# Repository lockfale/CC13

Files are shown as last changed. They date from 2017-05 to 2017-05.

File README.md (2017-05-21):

# CC13:
CarolinaCon13 Badge Jank

## Files:
- CC13 Badge.pdf - Detailed badge assembly guide
- ino files

## If you need to setup an Arduino build environment:

Download the latest Arduino archive from https://www.arduino.cc/en/Main/Software

Uncompress archive: xz --decompress arduino-1.8.2-linux64.tar.xz

As root untar in /usr/local and create symlink:
```
    # cd /usr/local
    # tar xvf ~/Downloads/arduino-1.8.2-linux64.tar
    # ln -s arduino-1.8.2/ arduino
```

As regular user, download badge code into home directory (--recursive will pull down dependency projects):
```
    cd
    git clone --recursive https://github.com/lockfale/CC13.git
```

## LED Patterns

To add an LED pattern:
  # In `badge/led.cpp`:
    ## Add a `const byte` array to with its own name and each sequential animation state of your desired LED pattern in binary format matching the number of LEDs in each entry.
    ## Add a branch to the `changePattern` function.
    ## Add a function for it at the bottom.
  # In `badge/led.h`:
    ## Add a function for it at the bottom.
  # In `badge/setup.cpp`:
    ## Add a submenu command for it.

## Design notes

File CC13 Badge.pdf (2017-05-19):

# CarolinaCon 13 Badge Guide

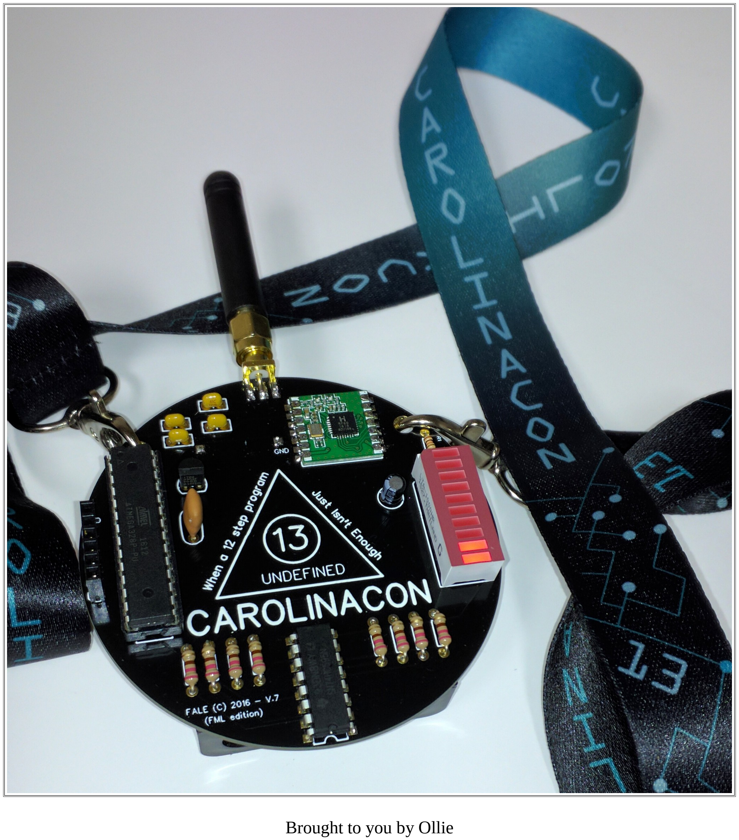
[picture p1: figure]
Brought to you by Ollie

Hello you lovely hackers, crackers, and slackers. Welcome to another year of CarolinaCon.

We'll skip over the 'how to solder' portion of the guide. If you've never soldered before don't feel bad as there should be plenty of folks in the Hardware Hacking Village willing to walk you along.

First off make sure your bag has the proper bits:

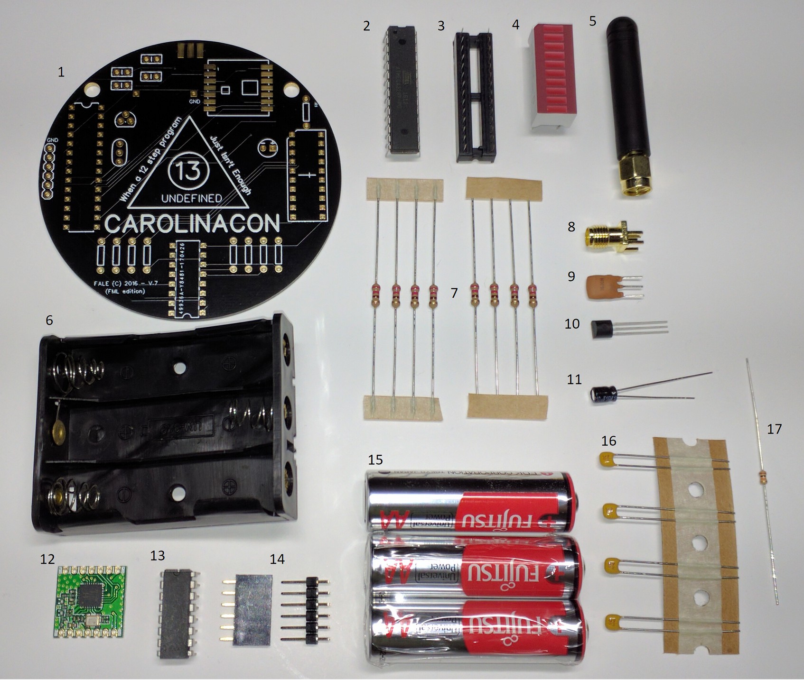
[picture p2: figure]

1. Badge*
2. Atmel Chip
3. Chip Socket
4. LED Array
5. Antenna
6. Battery Holder
7. 8x 220ohm Resistor
8. Connector for Antenna**
9. Timing Crystal
10. 3.3v Regulator
11. Electrolytic Capacitor
12. Transceiver Chip
13. Shift Register
14. Male & Female Headers
15. 3x AA Batteries
16. 4x Polymer Capacitors
17. 10k Resistor

Replacements are available for missing or broken parts but quantity is limited on some items.

* | Yours most likely isn't as cool as this one, probably green or something.
** | If you were late to reregistration you may regretfully have gotten a bag without a SMA
| Connector for the Antenna. Your badge can still play with the others but you will have a wire
| Antenna instead.

These parts can be soldered in any order but I would suggest the ones that are directional first.

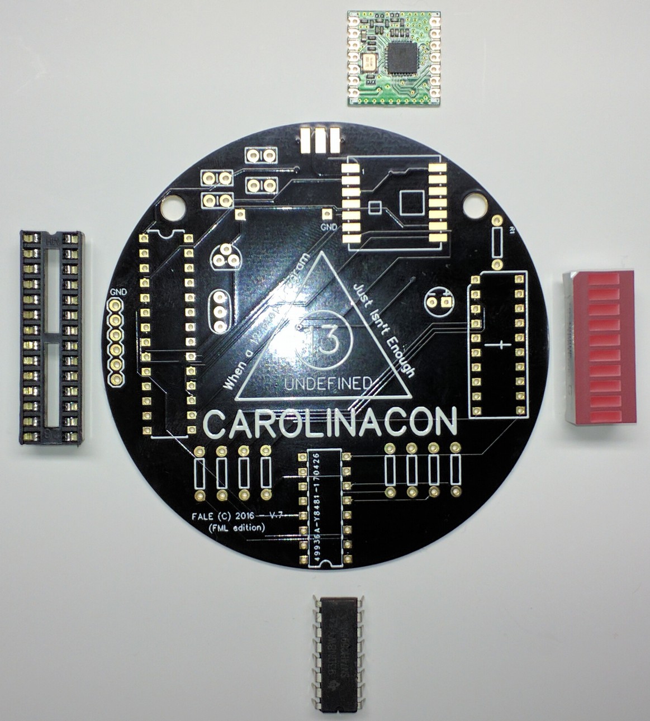
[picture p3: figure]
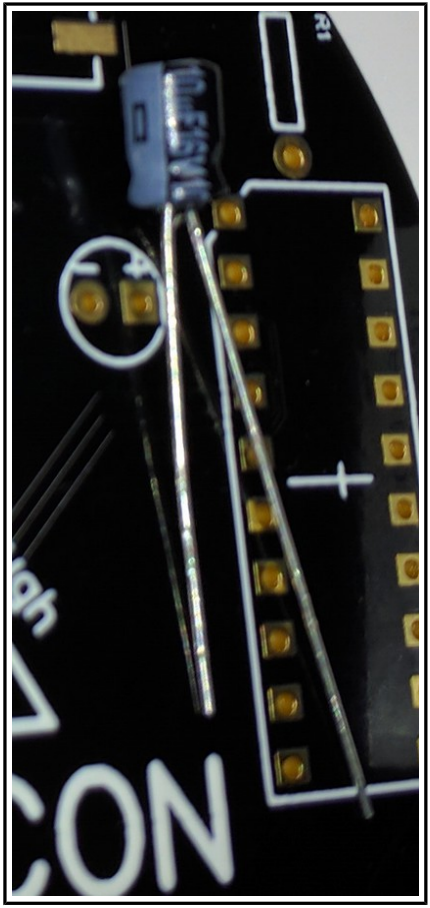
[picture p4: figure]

The Chip Socket, Shift Register, Led Array, and Transceiver Chip all have illustrations on the board to ensure that they are set in the right direction.

The Electrolytic Capacitor has a gray bar down one side that indicates the negative lead.

Finished product:

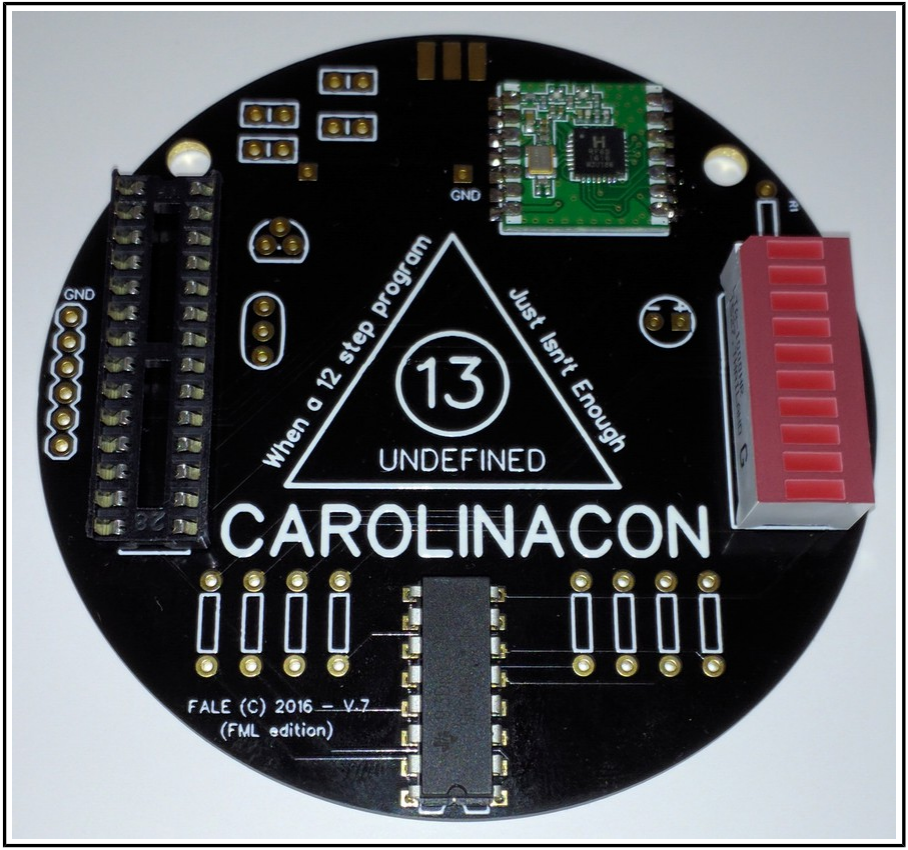
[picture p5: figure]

It should be noted that it is not a good idea to insert the Atmel Chip into the socket until the rest of the badge is finished and the Atmel Chip has had its boot loader installed. This can be done by the guys in the Hardware Hacking Village.

Next step is the rest of the badge:

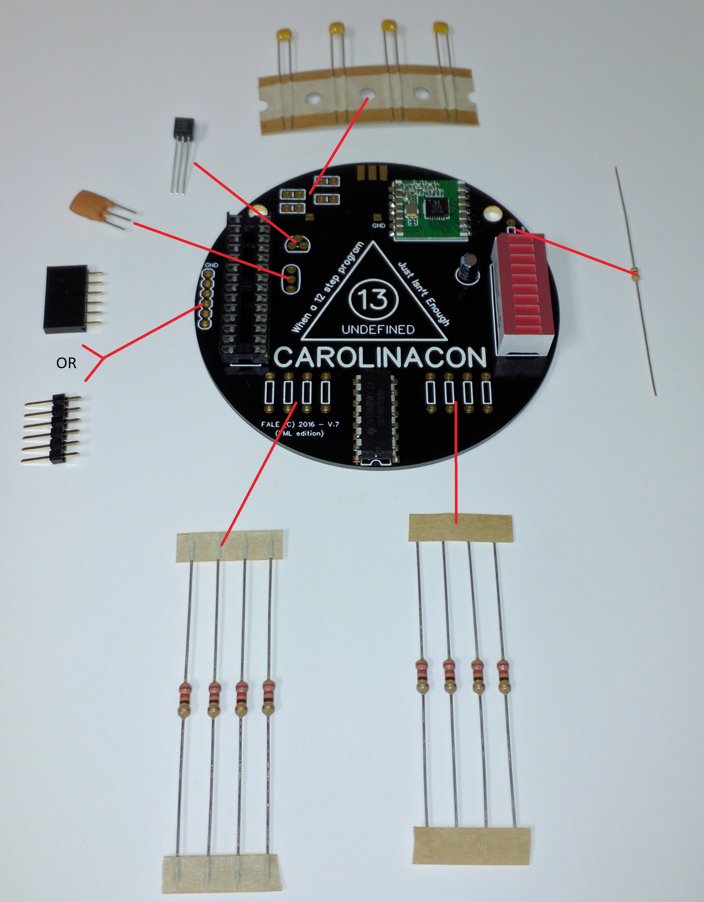
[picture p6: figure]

On the Voltage Regulator make sure the middle leg goes to the single pin well towards the top of the badge and the outer legs go to their respective pin wells bellow it. The Timing Crystal, Resistors, and Polymer Capacitors can be inserted in any direction.

Use the Female Header if you want to program the badge using the equipment provided. Use the Male Header if you have your own ideas for the badge.

Next step is the antenna:

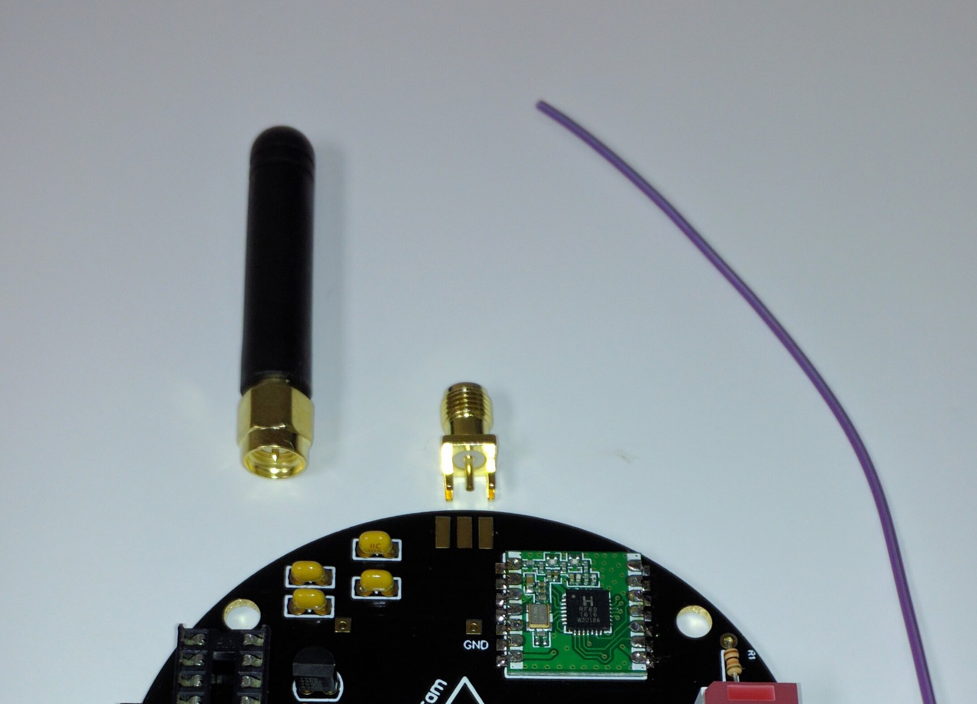
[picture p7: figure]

If you have the SMA connector solder the side with three prongs to the strip of three solder points at the top of the badge. If you only have a wire antenna, strip a 1/8th inch section and solder that to the middle solder joint on the top. Liberal use of adhesive is suggested to keep the wire antenna attached by more than just the solder.

Next is the battery pack:

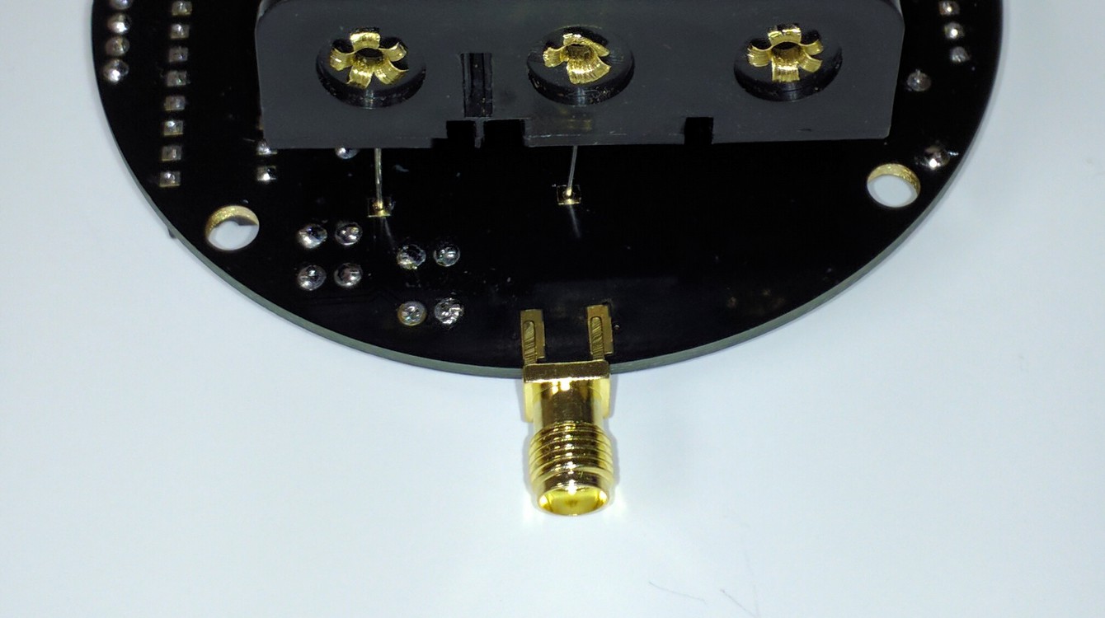
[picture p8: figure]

On the reverse side of the badge you will only have two pin wells left, the battery pack leads go through here. You can also solder the other side of the SMA connector at this time. Double sided tape will be available at the Hardware Hacking Village to secure the battery pack to the badge.

Your badge is finished as far as the hardware is concerned, now all that’s left is to flash some software, either what our volunteers have provided or some home brew of your own.

Have fun and welcome to CC13.

- Ollie the Miniature Australian Shepherd.

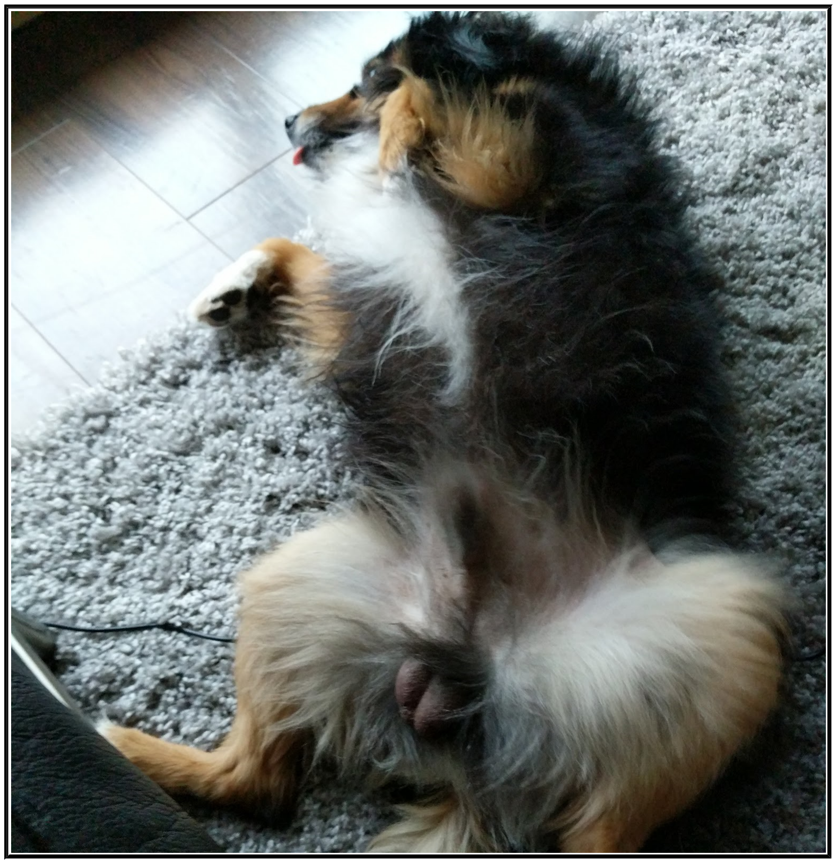
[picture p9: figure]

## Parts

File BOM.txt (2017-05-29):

1x IC 8-BIT SHIFT REGISTER 16-DIP 	- SN74HC595N 		- DIGIKEY PART NUMBER 296-1600-5-ND 
1x CONN IC DIP SOCKET 28POS TIN   	- ED281DT	 		- DIGIKEY PART NUMBER ED3050-5-ND
1x IC MCU 8BIT 32KB FLASH 28DIP		- ATMEGA328P-PU   	- DIGIKEY PART NUMBER ATMEGA328P-PU-ND
4x CAP CER 0.1UF 50V Y5V RADIAL		- K104Z15Y5VF5TL2 	- DIGIKEY PART NUMBER BC1160CT-ND 
1x CER RES 16.0000MHZ 30PF 			- ZTT-16.00MX		- X908-ND 
1x LED BAR GRAPH 10-SEGMENT RED		- LTA-1000HR		- 160-1066-ND 
1x RES 10K OHM 1/6W 5% AXIAL		- CFR-12JB-52-10K	- 10KEBK-ND
8x RES 220 OHM 1/4W 5% AXIAL		- CF14JT220R		- CF14JT220RCT-ND 
1x IC REG LDO 3.3V 0.25A TO92-3		- MCP1702-3302E/TO 	- MCP1702-3302E/TO-ND 
1x CAP ALUM 10UF 20% 16V RADIAL		- ECE-A1CKS100		- P966-ND
1x tranciever http://www.anarduino.com/details.jsp?pid=146
PCB edge mount female SMA connector, no part number, check amazon or ebay.
any 3 cell AAA or AA battery holder should work, find one with wire leads to ensure compatability.
any 8 pin .1" spacing male or female header for the FTDI connector.

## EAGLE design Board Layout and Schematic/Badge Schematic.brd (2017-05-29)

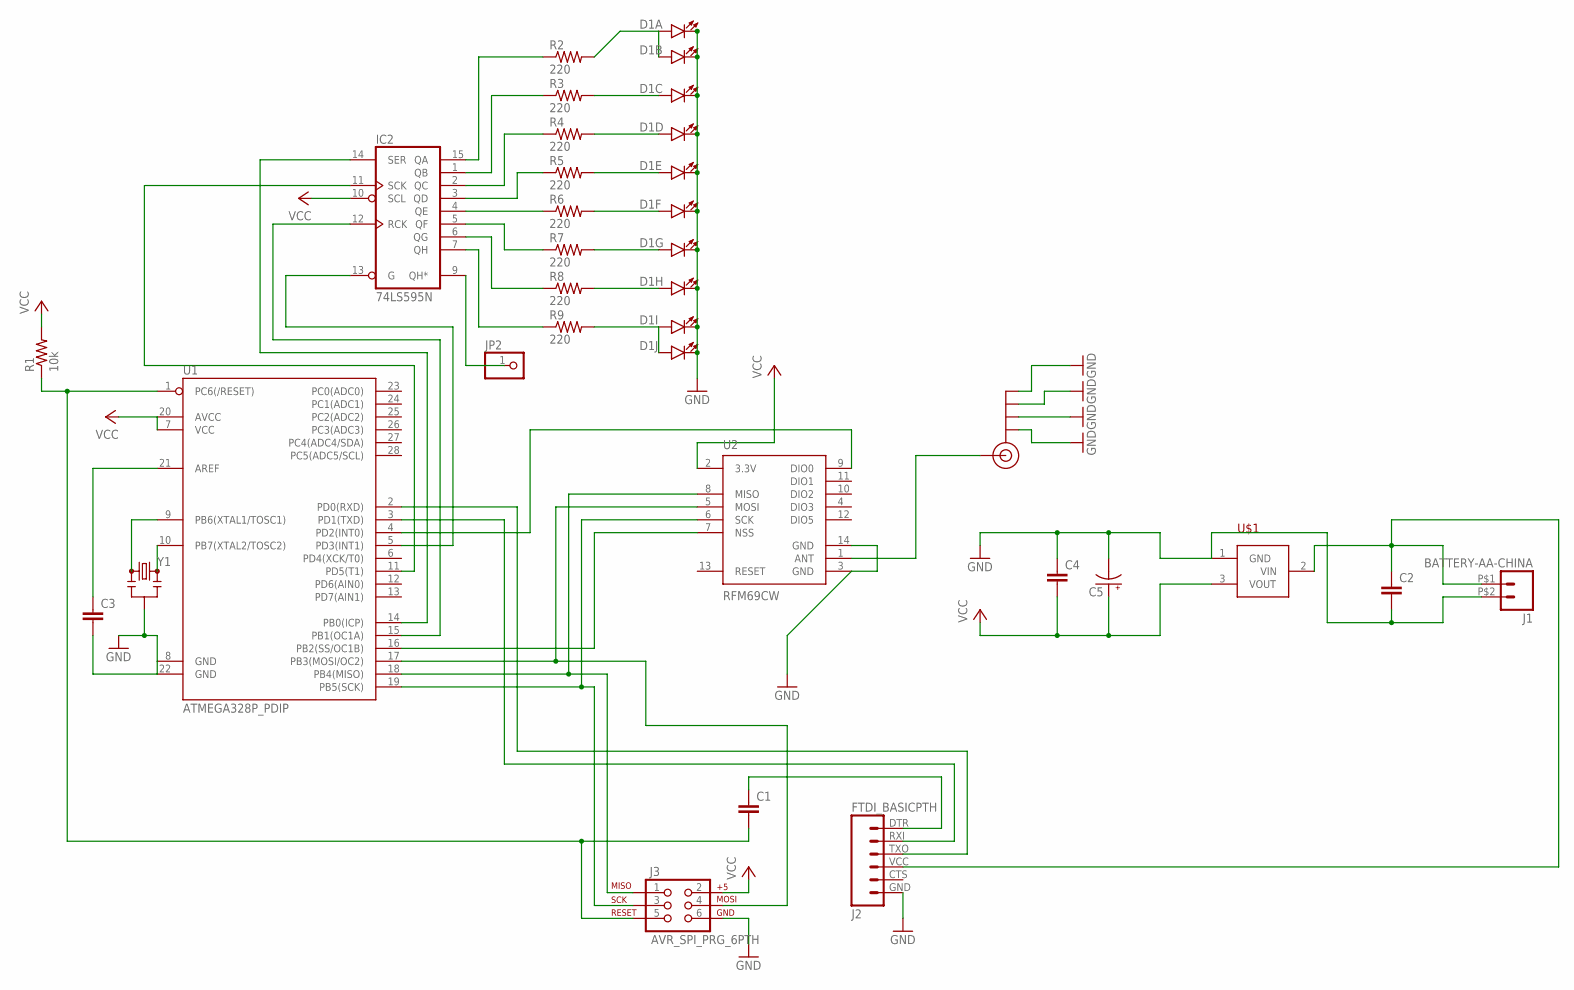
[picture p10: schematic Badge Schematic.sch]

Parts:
C1, C2, C3, C4: 0.1UF-50V-20%(PTH)KIT-EZ; CAP-PTH-SMALL-KIT
C5: 10UF-25V-20%(PTH)KIT; CPOL-RADIAL-10UF-25V-KIT
D1: LED_BARGRAPH_10; LED_BARGAPH_10
IC2: 74LS595N; DIL16
J1: BATTERY-AA-CHINA; BATTERY-AA-CHINA-PACKAGE
J2: FTDI_BASICPTH; FTDI_BASIC
J3: AVR_SPI_PRG_6PTH; 2X3
J$1: SMA_EDGE; SMA-EDGE
JP2: PINHD-1X1; 1X01
R1: 10k; AXIAL-0.3
R2, R3, R4, R5, R6, R7, R8, R9: 220; AXIAL-0.3EZ
U1: ATMEGA328P_PDIP; DIL28-3
U2: RFM69CW; RFM69CW-XXXS2
U$1: MCP1702-33TO92; TO-92
Y1: RESONATORPTH; RESONATOR-PTH

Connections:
GND: C2.2, C3.2, C4.1, C5.2 (-), D1.11 (C), D1.12 (C), D1.13 (C), D1.14 (C), D1.15 (C), D1.16 (C), D1.17 (C), D1.18 (C), D1.19 (C), D1.20 (C), IC2.8 (GND), J1.P$2 (2), J2.GND (6), J3.6, J$1.GND@0 (GND), J$1.GND@1 (GND), J$1.GND@2 (GND), J$1.GND@3 (GND), U1.8 (GND), U1.22 (GND), U2.3 (GND), U2.14 (GND), U$1.1 (GND), Y1.2
unnamed: J$1.SIG (SIGNAL), U2.1 (ANT)
unnamed: J3.4, U1.17 (PB3(MOSI/OC2)), U2.5 (MOSI)
unnamed: J3.1, U1.18 (PB4(MISO)), U2.8 (MISO)
unnamed: J3.3, U1.19 (PB5(SCK)), U2.6 (SCK)
unnamed: U1.4 (PD2(INT0)), U2.9 (DIO0)
unnamed: U1.16 (PB2(SS/OC1B)), U2.7 (NSS)
unnamed: IC2.13 (G), U1.5 (PD3(INT1))
unnamed: C1.1, J2.DTR (1)
unnamed: U1.10 (PB7(XTAL2/TOSC2)), Y1.3
unnamed: J2.TXO (3), U1.2 (PD0(RXD))
unnamed: J2.RXI (2), U1.3 (PD1(TXD))
unnamed: U1.9 (PB6(XTAL1/TOSC1)), Y1.1
unnamed: C2.1, J1.P$1 (1), J2.VCC (4), U$1.2 (VIN)
unnamed: IC2.7 (QH), R9.P$1 (1)
unnamed: IC2.15 (QA), R2.P$1 (1)
unnamed: IC2.6 (QG), R8.P$1 (1)
unnamed: IC2.5 (QF), R7.P$1 (1)
unnamed: C3.1, U1.21 (AREF)
unnamed: IC2.4 (QE), R6.P$1 (1)
unnamed: C1.2, J3.5, R1.P$1 (1), U1.1 (PC6(/RESET))
unnamed: IC2.3 (QD), R5.P$1 (1)
unnamed: IC2.2 (QC), R4.P$1 (1)
unnamed: IC2.1 (QB), R3.P$1 (1)
unnamed: D1.1 (A), D1.2 (A), R2.P$2 (2)
unnamed: D1.3 (A), R3.P$2 (2)
unnamed: D1.4 (A), R4.P$2 (2)
unnamed: D1.5 (A), R5.P$2 (2)
unnamed: D1.6 (A), R6.P$2 (2)
unnamed: D1.7 (A), R7.P$2 (2)
unnamed: D1.8 (A), R8.P$2 (2)
unnamed: D1.9 (A), D1.10 (A), R9.P$2 (2)
unnamed: IC2.14 (SER), U1.14 (PB0(ICP))
unnamed: IC2.12 (RCK), U1.15 (PB1(OC1A))
unnamed: IC2.11 (SCK), U1.11 (PD5(T1))
unnamed: IC2.9 (QH*), JP2.1
VCC: C4.2, C5.1 (+), IC2.10 (SCL), IC2.16 (VCC), J3.2, R1.P$2 (2), U1.7 (VCC), U1.20 (AVCC), U2.2 (3.3V), U$1.3 (VOUT)

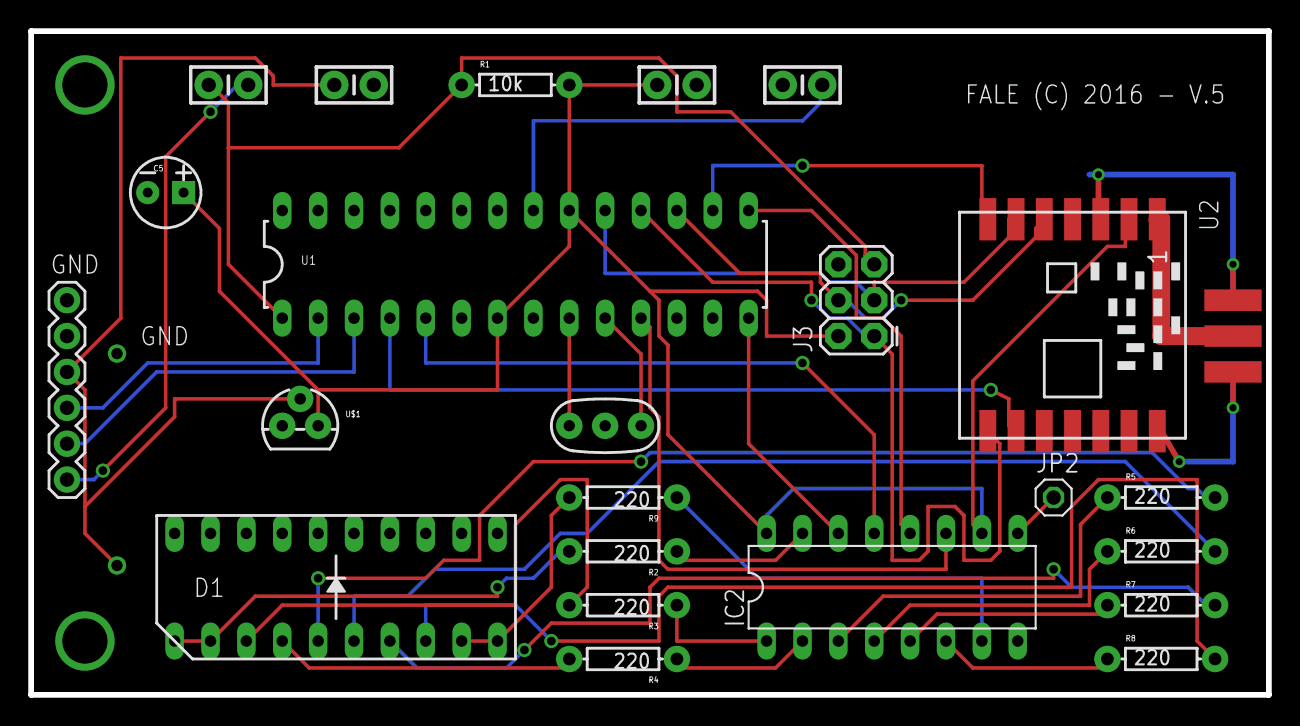
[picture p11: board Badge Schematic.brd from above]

Board: 2 copper layers, 87.6 x 47.0 mm, 25 parts (0 on the bottom side), 37 nets.

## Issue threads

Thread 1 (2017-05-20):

Missing SerialUI.h

snuffeluffegus, 2017-05-20:
wtf volvo why no SerialUI.h

pls give

melvin2001, 2017-05-20:
have you tried turning it off and on again

pandatrax, 2017-05-22:
Rebooted. This is fine.

Pysis868, 2017-05-24:
**Solved now**

..... Why am **I** getting this now?!

```
~/P/C/badge (master ⚡↩☡=) make
-------------------------
Arduino.mk Configuration:
- [AUTODETECTED]       CURRENT_OS = MAC
- [USER]               ARDUINO_DIR = /Applications/Arduino.app/Contents/Java
- [USER]               ARDMK_DIR = ../Arduino-Makefile//../Arduino-Makefile//../Arduino-Makefile
- [AUTODETECTED]       ARDUINO_VERSION = 182
- [DEFAULT]            ARCHITECTURE = avr
- [DEFAULT]            ARDMK_VENDOR = arduino
- [AUTODETECTED]       ARDUINO_PREFERENCES_PATH = /Users/Pysis/Library/Arduino15/preferences.txt
- [AUTODETECTED]       ARDUINO_SKETCHBOOK = /Users/Pysis/Documents/Arduino (from arduino preferences file)
- [BUNDLED]            AVR_TOOLS_DIR = /Applications/Arduino.app/Contents/Java/hardware/tools/avr (in Arduino distribution)
- [COMPUTED]           ARDUINO_LIB_PATH = /Applications/Arduino.app/Contents/Java/libraries (from ARDUINO_DIR)
- [COMPUTED]           ARDUINO_PLATFORM_LIB_PATH = /Applications/Arduino.app/Contents/Java/hardware/arduino/avr/libraries (from ARDUINO_DIR)
- [COMPUTED]           ARDUINO_VAR_PATH = /Applications/Arduino.app/Contents/Java/hardware/arduino/avr/variants (from ARDUINO_DIR)
- [COMPUTED]           BOARDS_TXT = /Applications/Arduino.app/Contents/Java/hardware/arduino/avr/boards.txt (from ARDUINO_DIR)
- [USER]               USER_LIB_PATH = /Users/Pysis/Programming/CC13/libraries
- [DEFAULT]            PRE_BUILD_HOOK = pre-build-hook.sh
- [USER]               BOARD_SUB = atmega328
- [USER]               BOARD_TAG = diecimila
- [COMPUTED]           CORE = arduino (from build.core)
- [COMPUTED]           VARIANT = standard (from build.variant)
- [COMPUTED]           OBJDIR = build-diecimila-atmega328 (from BOARD_TAG)
- [COMPUTED]           ARDUINO_CORE_PATH = /Applications/Arduino.app/Contents/Java/hardware/arduino/avr/cores/arduino (from ARDUINO_DIR, BOARD_TAG and boards.txt)
- [USER]               MONITOR_BAUDRATE = 115200
- [DEFAULT]            OPTIMIZATION_LEVEL = s
- [DEFAULT]            MCU_FLAG_NAME = mmcu
- [DEFAULT]            CFLAGS_STD = -std=gnu11 -flto -fno-fat-lto-objects
- [DEFAULT]            CXXFLAGS_STD = -std=gnu++11 -fno-threadsafe-statics -flto
- [COMPUTED]           DEVICE_PATH = /dev/ttyUSB0 (from MONITOR_PORT)
- [DEFAULT]            FORCE_MONITOR_PORT =
- [AUTODETECTED]       Size utility: AVR-aware for enhanced output
-
-                      ARDUINO_LIBS =
- [USER]                 EEPROMex
- [USER]                 RFM69
- [USER]                 SPIFlash
- [PLATFORM]             SPI
- [COMPUTED]           BOOTLOADER_PARENT = /Applications/Arduino.app/Contents/Java/hardware/arduino/avr/bootloaders (from ARDUINO_DIR)
- [COMPUTED]           ARDMK_VERSION = 1.5
- [COMPUTED]           CC_VERSION = 4.9.2 (avr-gcc)
-------------------------
mkdir -p build-diecimila-atmega328
/Applications/Arduino.app/Contents/Java/hardware/tools/avr/bin/avr-g++ -MMD -c -mmcu=atmega328p -DF_CPU=16000000L -DARDUINO=182 -DARDUINO_ARCH_AVR -D__PROG_TYPES_COMPAT__ -I/Applications/Arduino.app/Contents/Java/hardware/arduino/avr/cores/arduino -I/Applications/Arduino.app/Contents/Java/hardware/arduino/avr/variants/standard    -I/Applications/Arduino.app/Contents/Java/hardware/arduino/avr/libraries/SPI/src   -I/Users/Pysis/Programming/CC13/libraries/EEPROMex   -I/Users/Pysis/Programming/CC13/libraries/RFM69   -I/Users/Pysis/Programming/CC13/libraries/SPIFlash -Wall -ffunction-sections -fdata-sections -Os -fdiagnostics-color -fpermissive -fno-exceptions -std=gnu++11 -fno-threadsafe-statics -flto callbacks.cpp -o build-diecimila-atmega328/callbacks.cpp.o
callbacks.cpp:2:22: fatal error: SerialUI.h: No such file or directory
 #include <SerialUI.h>
                      ^
compilation terminated.
make: *** [build-diecimila-atmega328/callbacks.cpp.o] Error 1
~/P/C/badge (master ⚡↩☡=) locate 'SerialUI.h'
~/P/C/badge (master ⚡↩☡=) sudo find / -iname 'SerialUI.h'
Password:
... (Not found)
```

At 2050bb191be592012bb61ba0972d08d0176c64e8 with changes.

Mac 10.12.4, fish, version 2.5.0.

**Update**
After some overcomplicated work [StackOverflow - How to pull a new submodule](https://stackoverflow.com/questions/44105166/how-to-pull-a-new-submodule/44115382#44115382)
 eventually adding the missing submodule, clearing my `.gitmodules` files, and pulling from the GitHub upstream remote, I was able to continue my work.

Closed 2017-05-22.

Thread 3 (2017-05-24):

EEPROMex.cpp.o: No such file or directory

Pysis868, 2017-05-24:
```
~/P/C/badge (master ⚡→↩☡=) make upload
-------------------------
Arduino.mk Configuration:
- [AUTODETECTED]       CURRENT_OS = MAC
- [USER]               ARDUINO_DIR = /Applications/Arduino.app/Contents/Java
- [USER]               ARDMK_DIR = ../Arduino-Makefile//../Arduino-Makefile//../Arduino-Makefile
- [AUTODETECTED]       ARDUINO_VERSION = 182
- [DEFAULT]            ARCHITECTURE = avr
- [DEFAULT]            ARDMK_VENDOR = arduino
- [AUTODETECTED]       ARDUINO_PREFERENCES_PATH = /Users/Pysis/Library/Arduino15/preferences.txt
- [AUTODETECTED]       ARDUINO_SKETCHBOOK = /Users/Pysis/Documents/Arduino (from arduino preferences file)
- [BUNDLED]            AVR_TOOLS_DIR = /Applications/Arduino.app/Contents/Java/hardware/tools/avr (in Arduino distribution)
- [COMPUTED]           ARDUINO_LIB_PATH = /Applications/Arduino.app/Contents/Java/libraries (from ARDUINO_DIR)
- [COMPUTED]           ARDUINO_PLATFORM_LIB_PATH = /Applications/Arduino.app/Contents/Java/hardware/arduino/avr/libraries (from ARDUINO_DIR)
- [COMPUTED]           ARDUINO_VAR_PATH = /Applications/Arduino.app/Contents/Java/hardware/arduino/avr/variants (from ARDUINO_DIR)
- [COMPUTED]           BOARDS_TXT = /Applications/Arduino.app/Contents/Java/hardware/arduino/avr/boards.txt (from ARDUINO_DIR)
- [USER]               USER_LIB_PATH = /Users/Pysis/Programming/CC13/libraries
- [DEFAULT]            PRE_BUILD_HOOK = pre-build-hook.sh
- [USER]               BOARD_SUB = atmega328
- [USER]               BOARD_TAG = diecimila
- [COMPUTED]           CORE = arduino (from build.core)
- [COMPUTED]           VARIANT = standard (from build.variant)
- [COMPUTED]           OBJDIR = build-diecimila-atmega328 (from BOARD_TAG)
- [COMPUTED]           ARDUINO_CORE_PATH = /Applications/Arduino.app/Contents/Java/hardware/arduino/avr/cores/arduino (from ARDUINO_DIR, BOARD_TAG and boards.txt)
- [USER]               MONITOR_BAUDRATE = 115200
- [DEFAULT]            OPTIMIZATION_LEVEL = s
- [DEFAULT]            MCU_FLAG_NAME = mmcu
- [DEFAULT]            CFLAGS_STD = -std=gnu11 -flto -fno-fat-lto-objects
- [DEFAULT]            CXXFLAGS_STD = -std=gnu++11 -fno-threadsafe-statics -flto
- [COMPUTED]           DEVICE_PATH = /dev/tty.usbserial-12345678 (from MONITOR_PORT)
- [DEFAULT]            FORCE_MONITOR_PORT =
- [AUTODETECTED]       Size utility: AVR-aware for enhanced output
-
-                      ARDUINO_LIBS =
- [USER]                 EEPROMex
- [USER]                 RFM69
- [USER]                 SPIFlash
- [USER]                 SerialUI
- [PLATFORM]             SPI
- [COMPUTED]           BOOTLOADER_PARENT = /Applications/Arduino.app/Contents/Java/hardware/arduino/avr/bootloaders (from ARDUINO_DIR)
- [COMPUTED]           ARDMK_VERSION = 1.5
- [COMPUTED]           CC_VERSION = 4.9.2 (avr-gcc)
-------------------------
mkdir -p build-diecimila-atmega328
...
/Applications/Arduino.app/Contents/Java/hardware/tools/avr/bin/avr-gcc -MMD -c -mmcu=atmega328p -DF_CPU=16000000L -DARDUINO=182 -DARDUINO_ARCH_AVR -D__PROG_TYPES_COMPAT__ -I/Applications/Arduino.app/Contents/Java/hardware/arduino/avr/cores/arduino -I/Applications/Arduino.app/Contents/Java/hardware/arduino/avr/variants/standard    -I/Applications/Arduino.app/Contents/Java/hardware/arduino/avr/libraries/SPI/src   -I/Users/Pysis/Programming/CC13/libraries/EEPROMex   -I/Users/Pysis/Programming/CC13/libraries/RFM69   -I/Users/Pysis/Programming/CC13/libraries/SPIFlash   -I/Users/Pysis/Programming/CC13/libraries/SerialUI/src -Wall -ffunction-sections -fdata-sections -Os -x assembler-with-cpp -flto /Applications/Arduino.app/Contents/Java/hardware/arduino/avr/cores/arduino/wiring_pulse.S -o build-diecimila-atmega328/core/wiring_pulse.S.o
/Applications/Arduino.app/Contents/Java/hardware/tools/avr/bin/avr-gcc-ar rcs build-diecimila-atmega328/libcore.a  build-diecimila-atmega328/core/WInterrupts.c.o  build-diecimila-atmega328/core/hooks.c.o  build-diecimila-atmega328/core/wiring.c.o  build-diecimila-atmega328/core/wiring_analog.c.o  build-diecimila-atmega328/core/wiring_digital.c.o  build-diecimila-atmega328/core/wiring_pulse.c.o  build-diecimila-atmega328/core/wiring_shift.c.o  build-diecimila-atmega328/core/CDC.cpp.o  build-diecimila-atmega328/core/HardwareSerial.cpp.o  build-diecimila-atmega328/core/HardwareSerial0.cpp.o  build-diecimila-atmega328/core/HardwareSerial1.cpp.o  build-diecimila-atmega328/core/HardwareSerial2.cpp.o  build-diecimila-atmega328/core/HardwareSerial3.cpp.o  build-diecimila-atmega328/core/IPAddress.cpp.o  build-diecimila-atmega328/core/PluggableUSB.cpp.o  build-diecimila-atmega328/core/Print.cpp.o  build-diecimila-atmega328/core/Stream.cpp.o  build-diecimila-atmega328/core/Tone.cpp.o  build-diecimila-atmega328/core/USBCore.cpp.o  build-diecimila-atmega328/core/WMath.cpp.o  build-diecimila-atmega328/core/WString.cpp.o  build-diecimila-atmega328/core/abi.cpp.o  build-diecimila-atmega328/core/main.cpp.o  build-diecimila-atmega328/core/new.cpp.o  build-diecimila-atmega328/core/wiring_pulse.S.o    build-diecimila-atmega328/platformlibs/SPI/src/SPI.cpp.o   build-diecimila-atmega328/userlibs/Users/Pysis/Programming/CC13/libraries/EEPROMex/EEPROMex.cpp.o build-diecimila-atmega328/userlibs/Users/Pysis/Programming/CC13/libraries/RFM69/RFM69.cpp.o build-diecimila-atmega328/userlibs/Users/Pysis/Programming/CC13/libraries/RFM69/RFM69_ATC.cpp.o build-diecimila-atmega328/userlibs/Users/Pysis/Programming/CC13/libraries/RFM69/RFM69_OTA.cpp.o build-diecimila-atmega328/userlibs/Users/Pysis/Programming/CC13/libraries/SPIFlash/SPIFlash.cpp.o build-diecimila-atmega328/userlibs/Users/Pysis/Programming/CC13/libraries/SerialUI/src/Command.cpp.o build-diecimila-atmega328/userlibs/Users/Pysis/Programming/CC13/libraries/SerialUI/src/Delegate.cpp.o build-diecimila-atmega328/userlibs/Users/Pysis/Programming/CC13/libraries/SerialUI/src/DelegateDummy.cpp.o build-diecimila-atmega328/userlibs/Users/Pysis/Programming/CC13/libraries/SerialUI/src/MenuItem.cpp.o build-diecimila-atmega328/userlibs/Users/Pysis/Programming/CC13/libraries/SerialUI/src/Request.cpp.o build-diecimila-atmega328/userlibs/Users/Pysis/Programming/CC13/libraries/SerialUI/src/SUIMenu.cpp.o build-diecimila-atmega328/userlibs/Users/Pysis/Programming/CC13/libraries/SerialUI/src/SUIStateTracking.cpp.o build-diecimila-atmega328/userlibs/Users/Pysis/Programming/CC13/libraries/SerialUI/src/SerialUI.cpp.o build-diecimila-atmega328/userlibs/Users/Pysis/Programming/CC13/libraries/SerialUI/src/SovAPipe.cpp.o build-diecimila-atmega328/userlibs/Users/Pysis/Programming/CC13/libraries/SerialUI/src/SovAPlat_DigiUSB.cpp.o build-diecimila-atmega328/userlibs/Users/Pysis/Programming/CC13/libraries/SerialUI/src/SovAStreamBase.cpp.o build-diecimila-atmega328/userlibs/Users/Pysis/Programming/CC13/libraries/SerialUI/src/SovAStreamStandard.cpp.o build-diecimila-atmega328/userlibs/Users/Pysis/Programming/CC13/libraries/SerialUI/src/SovaStreamDigi.cpp.o build-diecimila-atmega328/userlibs/Users/Pysis/Programming/CC13/libraries/SerialUI/src/SubMenu.cpp.o
/Applications/Arduino.app/Contents/Java/hardware/tools/avr/bin/../lib/gcc/avr/4.9.2/../../../../avr/bin/ar: build-diecimila-atmega328/userlibs/Users/Pysis/Programming/CC13/libraries/EEPROMex/EEPROMex.cpp.o: No such file or directory
make: *** [build-diecimila-atmega328/libcore.a] Error 1
```

Mac 10.12.4, fish shell 2.5.0.

pandatrax, 2017-05-24:
There might be something going on with your OBJDIR. Can you do a make clean, then make again and send me the output?

Thanks

pandatrax, 2017-05-24:
Sweet! That looks more like what I was expecting. I wonder what made your OBJDIR change during linking. Glad the 'make clean' fixed it.

Pysis868, 2017-05-24:
I do have some Makefile changes coming your way ;).

btw I got the monitor to work as well!
There are just some very slight issues while using it.  Will open a new issue for it.

pandatrax, 2017-05-24:
Excellent.

I think that we should create separate makefiles for each platform, like here: https://github.com/ladislas/Bare-Arduino-Project

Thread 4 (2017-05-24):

Some upload script environment user interface issues

Pysis868, 2017-05-24:
Small issues:
- Input does not appear until enter is pressed.  It would be nice to see what is typed in case there is an error that needs reviewing, or I change my mind.
- It may help if menus appeared upon entering, and not just the help message, maybe every time an action completes.
- After a small delay, maybe 5 seconds, at least on my platform, I receive the message `Thanks for using SerialUI! Goodbye.`.  Of course the program runs in sort of a loop, but the current state is lost, which is annoying, and I did not want to exit yet.  I understand if this phenomenon is not completely under this project's control, but would appreciate any help in determining why it is happening.

Upon starting the monitor part of the Makefile:
```
~/P/C/badge (master ⚡→↩☡=) make monitor
<Arduino environment header>
<terminal clear>
Transmitting at 915 Mhz...
RFM69_ATC Enabled (Auto Transmission Control)

```
It will stay like this until key press.
Then this will appear:
```
+++ Welcome to CarolinaCon 13 +++
Enter '?' for options.
>
```
The input you type will not appear until you press Enter.
Then it will look like this:
```
+++ Welcome to CarolinaCon 13 +++
Enter '?' for options.
> ?
*** Help for: TOP

        + schedule            Print the schedule
        + flashy              Flashy flashy
        + radio               Radio Properties

        * quit                Exit SerialUI
        * ?                   List available menu items
>
```
More examples:
```
> radio
radio
radio>
```
```
radio> ?
*** Help for: radio

        * temp                Print Radio Temperature

        * ..                  Move up to parent menu
        * ?                   List available menu items
radio>
```

pandatrax, 2017-05-24:
Answers to small issues :)
- Echoing over Serial is not trivial. If you have code for it, please send it along.
- Having the current menu print after each command might be doable, let me look into it.
- That is a property of SerialUI. Have to look to see if there is a way to either extend the timeout or turn it off.

Pysis868, 2017-05-24:
- I will imply something is possible, and it resides somewhere in this project.  I can look into it later, but if you have at least the path and section address of the area to look at.
- Cool, and same as above if you can't get to it, maybe I can look at later as well.
- Would it not be possible from what you know to use the library and have a constant ping-pong (doesn't SSH do this?) communication until quit is sent or the connection is broken by say, the computer sleeping?

Again, thanks for the project to work on.  I can look into more details as I have time, but thought you would be able to at least add some quick and useful comments as the item was open, and I can just track the issues this way for others as well.

not-really-bart, 2017-05-25:
For #3, looks like you need to edit the following in badge/BadgeSettings.h:

+// serial_maxidle_ms -- how long before we consider the user
+// gone, for lack of activity (milliseconds)
+#define serial_maxidle_ms           30000
+
+// serial_readtimeout_ms -- timeout when we're expecting input
+// for a specific request/read (milliseconds)
+#define serial_readtimeout_ms       20000

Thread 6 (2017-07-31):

Board doesn't do light pattern or communicate after flashing eeprom

digital-shokunin, 2017-07-31:
What did I do wrong? The badge doesn't do anything when I reset it.

```surge@Kirabi:~/workspace/CC13/badge$ sudo make do_eeprom
-------------------------
Arduino.mk Configuration:
- [AUTODETECTED]       CURRENT_OS = LINUX
- [USER]               ARDUINO_DIR = /usr/local/arduino
- [USER]               ARDMK_DIR = /home/surge/workspace/CC13/Arduino-Makefile
- [AUTODETECTED]       ARDUINO_VERSION = 182
- [DEFAULT]            ARCHITECTURE = avr
- [DEFAULT]            ARDMK_VENDOR = arduino
- [AUTODETECTED]       ARDUINO_PREFERENCES_PATH = /home/surge/.arduino15/preferences.txt
- [AUTODETECTED]       ARDUINO_SKETCHBOOK = /home/surge/Arduino (from arduino preferences file)
- [BUNDLED]            AVR_TOOLS_DIR = /usr/local/arduino/hardware/tools/avr (in Arduino distribution)
- [COMPUTED]           ARDUINO_LIB_PATH = /usr/local/arduino/libraries (from ARDUINO_DIR)
- [COMPUTED]           ARDUINO_PLATFORM_LIB_PATH = /usr/local/arduino/hardware/arduino/avr/libraries (from ARDUINO_DIR)
- [COMPUTED]           ARDUINO_VAR_PATH = /usr/local/arduino/hardware/arduino/avr/variants (from ARDUINO_DIR)
- [COMPUTED]           BOARDS_TXT = /usr/local/arduino/hardware/arduino/avr/boards.txt (from ARDUINO_DIR)
- [USER]               USER_LIB_PATH = /home/surge/workspace/CC13/libraries
- [DEFAULT]            PRE_BUILD_HOOK = pre-build-hook.sh
- [USER]               BOARD_SUB = atmega328
- [USER]               BOARD_TAG = diecimila
- [COMPUTED]           CORE = arduino (from build.core)
- [COMPUTED]           VARIANT = standard (from build.variant)
- [COMPUTED]           OBJDIR = build-diecimila-atmega328 (from BOARD_TAG)
- [COMPUTED]           ARDUINO_CORE_PATH = /usr/local/arduino/hardware/arduino/avr/cores/arduino (from ARDUINO_DIR, BOARD_TAG and boards.txt)
- [USER]               MONITOR_BAUDRATE = 115200
- [DEFAULT]            OPTIMIZATION_LEVEL = s
- [DEFAULT]            MCU_FLAG_NAME = mmcu
- [DEFAULT]            CFLAGS_STD = -std=gnu11 -flto -fno-fat-lto-objects
- [DEFAULT]            CXXFLAGS_STD = -std=gnu++11 -fno-threadsafe-statics -flto
- [COMPUTED]           DEVICE_PATH = /dev/ttyUSB0 (from MONITOR_PORT)
- [DEFAULT]            FORCE_MONITOR_PORT =
- [AUTODETECTED]       Size utility: AVR-aware for enhanced output
-
-                      ARDUINO_LIBS =
- [USER]                 EEPROMex
- [USER]                 RFM69
- [USER]                 SPIFlash
- [USER]                 SerialUI
- [PLATFORM]             SPI
- [COMPUTED]           BOOTLOADER_PARENT = /usr/local/arduino/hardware/arduino/avr/bootloaders (from ARDUINO_DIR)
- [COMPUTED]           ARDMK_VERSION = 1.5
- [COMPUTED]           CC_VERSION = 4.9.2 (avr-gcc)
-------------------------
mkdir -p build-diecimila-atmega328
/usr/local/arduino/hardware/tools/avr/bin/avrdude -q -V -p atmega328p -C /usr/local/arduino/hardware/tools/avr/etc/avrdude.conf -D -c arduino -b 57600 -P /dev/ttyUSB0 \
		-U eeprom:w:build-diecimila-atmega328/badge.eep:i

avrdude: AVR device initialized and ready to accept instructions
avrdude: Device signature = 0x1e950f (probably m328p)
avrdude: reading input file "build-diecimila-atmega328/badge.eep"
avrdude: writing eeprom (0 bytes):
avrdude: 0 bytes of eeprom written

avrdude: safemode: Fuses OK (E:00, H:00, L:00)

avrdude done.  Thank you.

surge@Kirabi:~/workspace/CC13/badge$ sudo make do_upload
-------------------------
Arduino.mk Configuration:
- [AUTODETECTED]       CURRENT_OS = LINUX
- [USER]               ARDUINO_DIR = /usr/local/arduino
- [USER]               ARDMK_DIR = /home/surge/workspace/CC13/Arduino-Makefile
- [AUTODETECTED]       ARDUINO_VERSION = 182
- [DEFAULT]            ARCHITECTURE = avr
- [DEFAULT]            ARDMK_VENDOR = arduino
- [AUTODETECTED]       ARDUINO_PREFERENCES_PATH = /home/surge/.arduino15/preferences.txt
- [AUTODETECTED]       ARDUINO_SKETCHBOOK = /home/surge/Arduino (from arduino preferences file)
- [BUNDLED]            AVR_TOOLS_DIR = /usr/local/arduino/hardware/tools/avr (in Arduino distribution)
- [COMPUTED]           ARDUINO_LIB_PATH = /usr/local/arduino/libraries (from ARDUINO_DIR)
- [COMPUTED]           ARDUINO_PLATFORM_LIB_PATH = /usr/local/arduino/hardware/arduino/avr/libraries (from ARDUINO_DIR)
- [COMPUTED]           ARDUINO_VAR_PATH = /usr/local/arduino/hardware/arduino/avr/variants (from ARDUINO_DIR)
- [COMPUTED]           BOARDS_TXT = /usr/local/arduino/hardware/arduino/avr/boards.txt (from ARDUINO_DIR)
- [USER]               USER_LIB_PATH = /home/surge/workspace/CC13/libraries
- [DEFAULT]            PRE_BUILD_HOOK = pre-build-hook.sh
- [USER]               BOARD_SUB = atmega328
- [USER]               BOARD_TAG = diecimila
- [COMPUTED]           CORE = arduino (from build.core)
- [COMPUTED]           VARIANT = standard (from build.variant)
- [COMPUTED]           OBJDIR = build-diecimila-atmega328 (from BOARD_TAG)
- [COMPUTED]           ARDUINO_CORE_PATH = /usr/local/arduino/hardware/arduino/avr/cores/arduino (from ARDUINO_DIR, BOARD_TAG and boards.txt)
- [USER]               MONITOR_BAUDRATE = 115200
- [DEFAULT]            OPTIMIZATION_LEVEL = s
- [DEFAULT]            MCU_FLAG_NAME = mmcu
- [DEFAULT]            CFLAGS_STD = -std=gnu11 -flto -fno-fat-lto-objects
- [DEFAULT]            CXXFLAGS_STD = -std=gnu++11 -fno-threadsafe-statics -flto
- [COMPUTED]           DEVICE_PATH = /dev/ttyUSB0 (from MONITOR_PORT)
- [DEFAULT]            FORCE_MONITOR_PORT =
- [AUTODETECTED]       Size utility: AVR-aware for enhanced output
-
-                      ARDUINO_LIBS =
- [USER]                 EEPROMex
- [USER]                 RFM69
- [USER]                 SPIFlash
- [USER]                 SerialUI
- [PLATFORM]             SPI
- [COMPUTED]           BOOTLOADER_PARENT = /usr/local/arduino/hardware/arduino/avr/bootloaders (from ARDUINO_DIR)
- [COMPUTED]           ARDMK_VERSION = 1.5
- [COMPUTED]           CC_VERSION = 4.9.2 (avr-gcc)
-------------------------
/usr/local/arduino/hardware/tools/avr/bin/avrdude -q -V -p atmega328p -C /usr/local/arduino/hardware/tools/avr/etc/avrdude.conf -D -c arduino -b 57600 -P /dev/ttyUSB0 \
		-U flash:w:build-diecimila-atmega328/badge.hex:i

avrdude: AVR device initialized and ready to accept instructions
avrdude: Device signature = 0x1e950f (probably m328p)
avrdude: reading input file "build-diecimila-atmega328/badge.hex"
avrdude: writing flash (23112 bytes):
avrdude: 23112 bytes of flash written

avrdude: safemode: Fuses OK (E:00, H:00, L:00)

avrdude done.  Thank you.
```

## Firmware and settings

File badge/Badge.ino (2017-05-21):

#include <avr/pgmspace.h> 
#include <SPIFlash.h>
#include "BadgeSettings.h"
#include "Badge.h"
#include "savecfg.h"
#include "led.h"
#include "radio.h"

#define SBUFFERSIZE  64  // Serial Input Buffer size

#define SERIAL_BAUD  115200

unsigned long currentMillis = 0;

void setup()
{
  if (!SetupSerialUI()) {
    DIE_HORRIBLY(F("Problem during setup"));
  }
  initiateCfg();
  int p = cfgReadPatternID();
  LED::initiateLED();
  LED::changePattern(p);
  Radio::initiateRadio();
}

void loop()
{
  if (MySUI.checkForUser(heartbeat_function_period_ms)) {

    /* Keep handling the serial user's
    ** requests until they exit or timeout.
    */
    while (MySUI.userPresent()) {
      // actually respond to requests
      MySUI.handleRequests();
    }
  } else {
      // when no one is connected, we do our 
      // maintenance 'manually'
      doMaintenanceStuff();
  }
}

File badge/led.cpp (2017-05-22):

#include <avr/pgmspace.h>
#include "led.h"
#include "savecfg.h"

/* *** LED *** */
namespace LED {

int latchPin = 9;
int clockPin = 5;
int dataPin = 8;
int fadepin = 3;

const byte flash[] PROGMEM = {
  B00000000, B11111111
};
const byte bullet[] PROGMEM = {
  B00010001, B00100010, B01000100, B10001000
};
const byte radiate[] PROGMEM = {
  B00011000, B00100100, B01000010, B10000001, B00000000,
  B00000000
};
const byte negradiate[] PROGMEM = {
  B10000001, B01000010, B00100100, B00011000, B00000000,
  B00000000
};
const byte march[] PROGMEM = {
  B00000001, B00000010, B00000100, B00001000, B00010000,
  B00100000, B01000000, B10000000, B01000000, B00100000,
  B00010000, B00001000, B00000100, B00000010, B00000001
};
const byte negmarch[] PROGMEM = {
  B11111111, B11111110, B11111101, B11111011, B11110111,
  B11101111, B11011111, B10111111, B01111111, B11111111,
  B01111111, B10111111, B11011111, B11101111, B11110111,
  B11111011, B11111101, B11111110
};
const byte stackdots[] PROGMEM = {
  B00000000, B10000000, B01000000, B00100000, B00010000,
  B00001000, B00000100, B00000010, B00000001, B10000001,
  B01000001, B00100001, B00010001, B00001001, B00000101,
  B00000011, B10000011, B01000011, B00100011, B00010011,
  B00001011, B00000111, B10000111, B01000111, B00100111,
  B00010111, B00001111, B10001111, B01001111, B00101111,
  B00011111, B10011111, B01011111, B00111111, B10111111,
  B01111111, B11111111
};
const byte sparkle[] PROGMEM = {
  B00000001, B10000000, B00000010, B01000000, B00000100,
  B00100000, B00001000, B00010000
};
const int patternTimes[] = {20, 30, 50, 40, 20, 30, 20, 5};
const int patternLengths[] = {2, 4, 6, 6, 15, 18, 37, 8};

unsigned int patternTime;
unsigned long previousPatternMillis = 0;
byte patternLength = 0;
byte currPattern = 255;
byte patternState = 0;
char PatternBuf[40];

void initiateLED()
{
  pinMode(latchPin, OUTPUT);
  pinMode(dataPin, OUTPUT);
  pinMode(clockPin, OUTPUT);
  pinMode(fadepin, OUTPUT);
}

void changePattern(byte tmpPattern)
{
  if (tmpPattern != currPattern) {
    currPattern = tmpPattern;
    patternLength = patternLengths[currPattern];
    patternTime = patternTimes[currPattern];
    patternState = 0;
    if (currPattern == 0) {
      memcpy_P( PatternBuf, flash, patternLength );
    } else if (currPattern == 1) {
      memcpy_P( PatternBuf, bullet, patternLength );
    } else if (currPattern == 2) {
      memcpy_P( PatternBuf, radiate, patternLength );
    } else if (currPattern == 3) {
      memcpy_P( PatternBuf, negradiate, patternLength );
    } else if (currPattern == 4) {
      memcpy_P( PatternBuf, march, patternLength );
    } else if (currPattern == 5) {
      memcpy_P( PatternBuf, negmarch, patternLength );
    } else if (currPattern == 6) {
      memcpy_P( PatternBuf, stackdots, patternLength );
    } else if (currPattern == 7) {
      memcpy_P( PatternBuf, sparkle, patternLength );
    }
  }
}

void changeLED(unsigned long currMill)
{
  if (patternState >= patternLength) {
    patternState = 0;
  }
  if(currMill - previousPatternMillis >= patternTime)
  {
    previousPatternMillis = currMill;  // Remember the time
    digitalWrite(latchPin, LOW);
    shiftOut(dataPin, clockPin, MSBFIRST, PatternBuf[patternState]);
    digitalWrite(latchPin, HIGH);
    patternState++;
  }
}

void flashPattern()
{
  byte x = 0;
  changePattern(x);
  cfgUpdatePatternID(x);
}

void bulletPattern()
{
  byte x = 1;
  changePattern(x);
  cfgUpdatePatternID(x);
}

void radiatePattern()
{
  byte x = 2;
  changePattern(x);
  cfgUpdatePatternID(x);
}

void negradiatePattern()
{
  byte x = 3;
  changePattern(x);
  cfgUpdatePatternID(x);
}

void marchPattern()
{
  byte x = 4;
  changePattern(x);
  cfgUpdatePatternID(x);
}

void negmarchPattern()
{
  byte x = 5;
  changePattern(x);
  cfgUpdatePatternID(x);
}

void stackdotsPattern()
{
  byte x = 6;
  changePattern(x);
  cfgUpdatePatternID(x);
}

void sparklePattern()
{
  byte x = 7;
  changePattern(x);
  cfgUpdatePatternID(x);
}

} /* namespace LED */

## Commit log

2017-05-21 Added quick new LED pattern Sparkle! Adding this to work out the process, before we get into the advanced stuff.
    Didn't unit or integration test. Let's add some unit tests later so we don't need to push the code everytime and have the badge handy?
    Added guide for adding new LED patterns to the README.
    Sorry about the whitespaces edits... For the better??
    [led.cpp, setup.cpp]
2017-05-21 Fixing all the things
    [Badge.ino]
2017-05-22 Fixed Radiate2, now negradiate. For Justin
    [led.cpp, setup.cpp]
2017-05-29 adding BOM
    use this if you want to build your own.
2017-05-29 adding board schematic
    beta board schematic.
    [Badge Schematic.brd, Badge Schematic.sch]

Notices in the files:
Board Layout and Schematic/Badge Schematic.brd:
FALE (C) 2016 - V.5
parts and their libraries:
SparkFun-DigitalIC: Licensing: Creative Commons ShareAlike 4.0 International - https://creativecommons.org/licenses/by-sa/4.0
